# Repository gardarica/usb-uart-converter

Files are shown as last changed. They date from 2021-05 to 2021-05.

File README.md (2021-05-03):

## USB to UART converter with isolation barrier

The project was created for safe debugging of power converters and other devices operating with high voltage through the UART interface using the _printf_ function. For isolation, a digital isolator from Texas Instruments - _ISO7721DR_ with isolation voltage up to 1500V was chosen. The main converter is the popular _CP2102_ chip from Silabs.

The converter can use with microcontrollers and other devices with a logic level of 3.3V (STM32 and others) and 5V (ATmega and others), which makes it universal. Leveling is done by supplying voltage from the main board to the converter (VREF pin).

3D view

## Features:

* Type converter: *USB -> UART*
* Used IC: *CP2102*
* Isolation voltage: *1000 V*
* Logic level: *2.5, 3.3 and 5V*
* Temperature ranges: *-40...+85°С*

## Project structure:

* Hardware
    * docs - documentation for project: ВОМ, schematic, etc
    * hardware - source project for design PCB
    * manufacture - gerber files for order PCB
    * mechanical - source project for 3D design

## Assembly drawing

Assembly drawing

## Bill of materials

BOM

## License

All source files for the project are distributed under the [MIT](./LICENSE "Text of license") license and you can use the project for commercial activities. But you need remembering that the author of the project does not give any guarantees for the operability of the device or parts of the project and also does not bear no liability for claims or damages.

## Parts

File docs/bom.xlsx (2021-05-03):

Value | Designator | PartNumber | Manufacturer | Quantity | Comment
4.7μF | C1, C2, C5, C6 | CL10B475KQ8NQNC | Samsung | 4 | Ceramic capacitor, 4.7μF, X7R, ±10%, 6.3V, 0603, -55...+125°C
0.1μF | C3, C4, C7 | CL10B104KB8NNNL | Samsung | 3 | Ceramic capacitor, 0.1μF, X7R, ±10%, 50V, 0603, -55...+125°C
 | D1 | ISO7721DR | Texas Instruments | 1 | IC digital isolator, 100Mbps, 3000Vrms, 2.25...5.5V, -55...+125°C, 8-SOIC
 | D2 | CP2102N-A02-GQFN28 | Silicon Labs | 1 | IC usb-to-uart bridge, USB2.0, 3...3.6V, -40...+85°C, 28-VFQFN
 | FU1 | TR-0603HV500-R | Eaton | 1 | Electromechanics relay, 63VDC, 0.5A, case 0603,
1k | R1, R2, R10, R11 | RC0603JR-071KL | Yageo | 4 | Resistor film, 1k, ±5%, 0603, 0.1W, -55...+125°C
100R | R3, R4 | RC0603JR-07100RL | Yageo | 2 | Resistor film, 100R, ±5%, 0603, 0.1W, -55...+125°C
22R | R5, R6 | RC0603FR-0722RL | Yageo | 2 | Resistor film, 22R, ±1%, 0603, 0.1W, -55...+125°C
1k | R7 | RC0603FR-071KL | Yageo | 1 | Resistor film, 1k, ±1%, 0603, 0.1W, -55...+125°C
5k1 | R8, R9 | RC0603FR-075K1L | Yageo | 2 | Resistor film, 5k1, ±1%, 0603, 0.1W, -55...+125°C
 | VD1 | 150060YS75000 | Wurth | 1 | LED, 20mA, 2V, 0603, -55...+150°C
 | VD2 | 150060BS75000 | Wurth | 1 | LED, 20mA, 3.2V, 0603, -55...+150°C
 | VD3, VD4 | 150060VS75000 | Wurth | 2 | LED, 20mA, 2V, 0603, -55...+150°C
 | X1 | TYPE-C-31-M-12 | Korean Hroparts | 1 | USB Type C, 3A
 | X2 | PLS-4R | Connfly | 1 | Connector, 4pin, 2.54mm, 500VAC, 3A

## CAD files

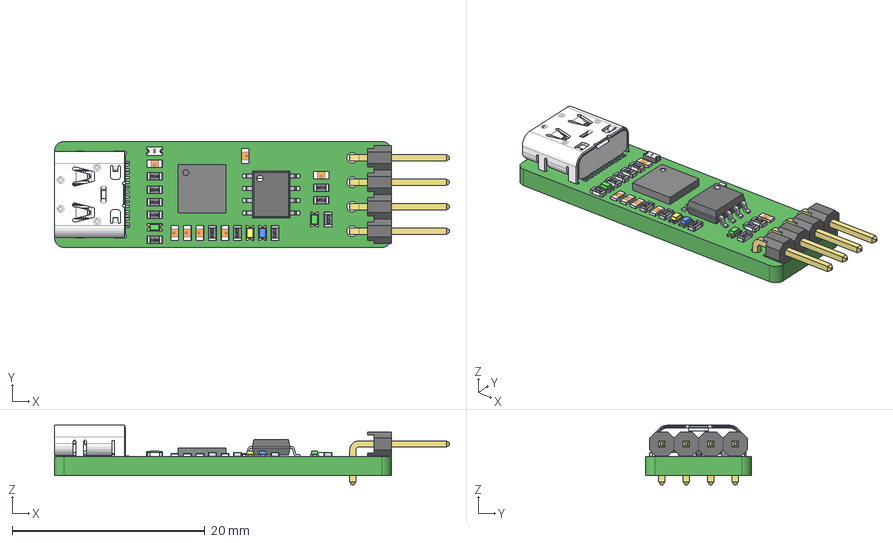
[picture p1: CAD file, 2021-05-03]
mechanical/3d-pcb.step
41.0 x 11.0 x 6.20 mm
PLS-R-pin x 4
User_Library-SOIC-8-1
User_Library-USB_-_C
User_Library-LED_0603_G_Pocket002 x 2
User_Library-LED_0603_G_Pad004 x 2
User_Library-LED_0603_G_Fillet x 2
User_Library-LED_0603_G_Pocket001 x 2
User_Library-LED_0603_G_Pad x 2
User_Library-LED_0603_B_Pocket002
User_Library-LED_0603_B_Pad004
User_Library-LED_0603_B_Fillet
User_Library-LED_0603_B_Pocket001
User_Library-LED_0603_B_Pad
User_Library-LED_0603_Y_Pocket002
User_Library-LED_0603_Y_Pad004
User_Library-LED_0603_Y_Fillet
User_Library-LED_0603_Y_Pocket001
User_Library-LED_0603_Y_Pad
chip_0603_r x 11
User_Library-MF-FSMF020X_FUSE0603
Open_CASCADE_STEP_translator_6.8_17.1
Open_CASCADE_STEP_translator_6.8_17.2.1
Thermal_Shape
Pin_Shape x 28
SW3dPS-0603_SMD_Capacitor x 7

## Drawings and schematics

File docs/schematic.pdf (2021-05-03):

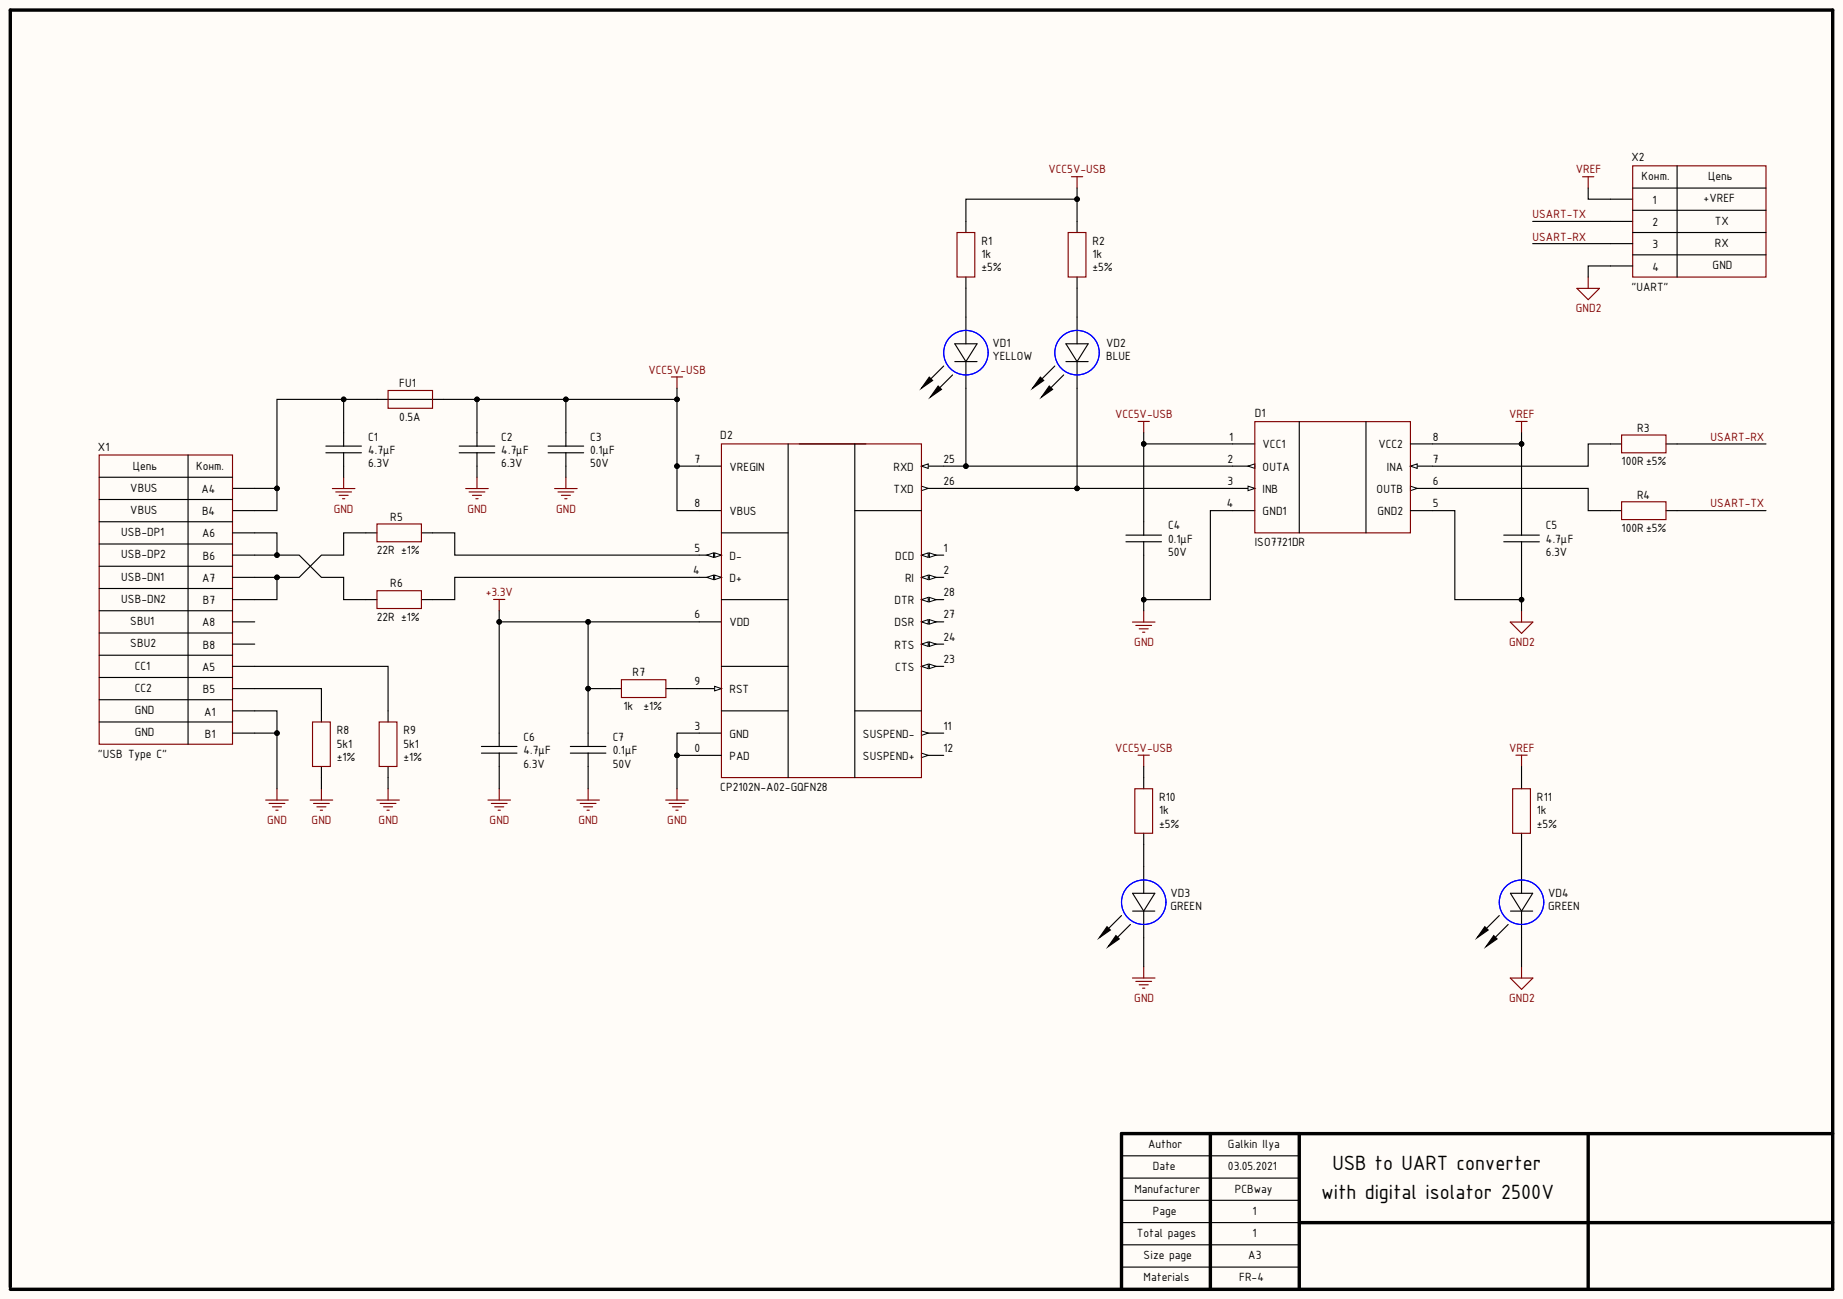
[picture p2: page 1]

Конт . | Цепь

Цепь | Конт .
VB U S | A4B4

U S B-D P 2
U S B-D N 1 | A7B7

U S B-D N 2
S B U 1 | A8B8 | 22R

R 7 | G N D N D VCC5V-U VREF

S B U 2
CC1 | A5B5

03.05.2021 PCBway 11

USB to UART converter
with digital isolator 2500V

Manufacturer Page Total pages

Materials Size page | A3

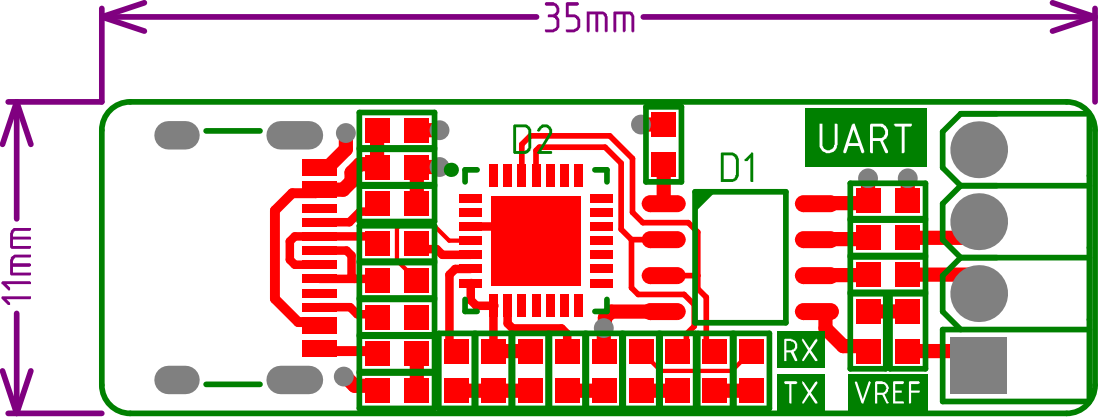
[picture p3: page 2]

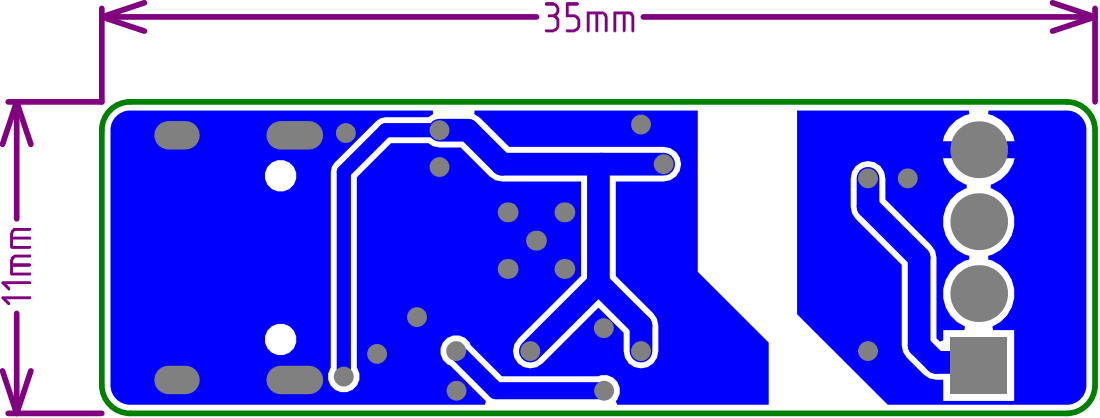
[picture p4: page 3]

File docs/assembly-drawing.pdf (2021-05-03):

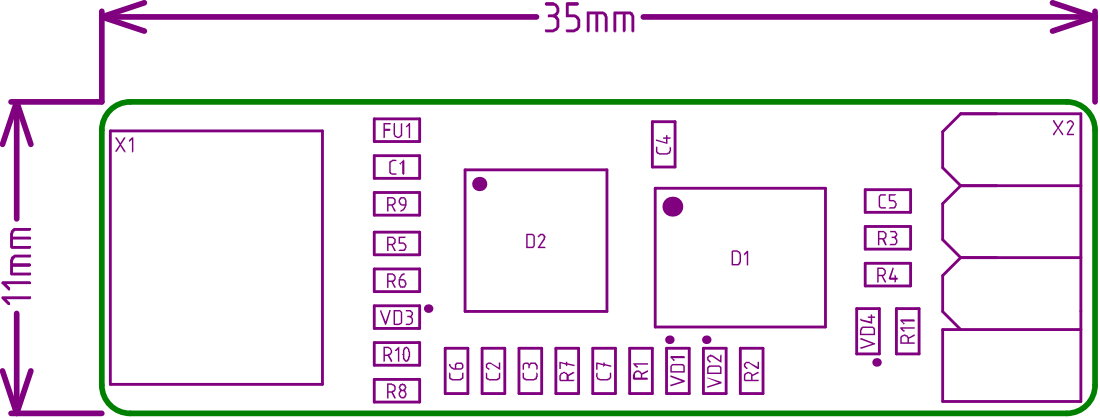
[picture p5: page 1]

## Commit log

2019-10-12 docs: Добавил файлы readme и gitignore для исключения логов AD
2019-10-12 new: Создал проект в AD и завершил принципиальную схему
    - В качестве самого преобразователя usb-uart выбрал
    популярную микросхему CP2102, которую обкатал во
    многих проектах и ее легко купить на lcsc;
    - В качестве изолятора выбрал ISO7721 из соображений
    доступности, т.к. легко купить на lcsc по адекватной
    цене и обеспечивает требуемые 2500В изоляции;
    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
    [PcbForConverter.PcbDoc, UsbToUart.SchDoc, UsbToUartConverter.PrjPcb]
2019-10-13 new: Завершил трассировку печатной платы. Требуется ревью
    [PcbForConverter.PcbDoc, UsbToUart.SchDoc]
2019-10-13 new: Выполнил ревью, исправил ошибки via т добавил OutJob файл
    [PcbForConverter.PcbDoc, UsbToUartConverter.PrjPcb]
2019-10-13 docs: Добавил в readme рендер 3D модели печатной платы для наглядности
2019-10-14 docs: Сгенерировал и добавил в проект документацию
    - Добавил в PDF принципиальную схему устройства;
    - Добавил BOM в excel
    - Выгрузил 3D модель устройства в формате step
    - Сформировал архив в Manufacturer для заказа печатных плат
    - Добавил сборочный чертеж в PDF
    - Добавил в readme информацию о ВОМ и возможных заменах
    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
    [3DForConverter.step, BOM.xlsx, PcbForConverter.PcbDoc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]
2019-10-16 new: Добавил проект и gerber файлы для заказа панели
    Я решил заказать 100 плат, для удобства монтажа решил
    собрать панель 5х2 плат, т.к. платы имеют малый размер
    (30х11 мм) и монтаж по штучно будет медленный и неудобный.
    При собранной панели операция по установки компонентов на
    pick and place машине займет очень мало времени.
    Панель собрано с соблюдением всех технологических требований
    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
    [PCB1.PcbDoc, Sborka.PrjPcb]
2019-11-27 docs: Обновил информацию о проекте, добавил фото собранных устройств
2019-11-29 docs: Исправил значение напряжения изоляции с 2500 до правильных 1500В
2020-03-28 docs: Обновил информацию о проекте в readme
2021-05-03 refactor: Обновил структуру проекта и нейминг файлов и папок
    [3d-pcb.step, PCB1.PcbDoc, Sborka.PrjPcb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]
2021-05-03 new: Add project source for HW rev 1.1 with new connectors
    [pcb.PcbDoc, usb-to-uart.SchDoc, usb-uart-converter.PrjPcb]
2021-05-03 docs: Add documentation and fabric files for HW rev 1.1
    [3d-pcb.step, PCB1.PcbDoc, Sborka.PrjPcb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]
